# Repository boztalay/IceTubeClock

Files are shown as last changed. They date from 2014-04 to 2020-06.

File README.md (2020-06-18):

IceTubeClock
============

A clock with ice tubes for its display

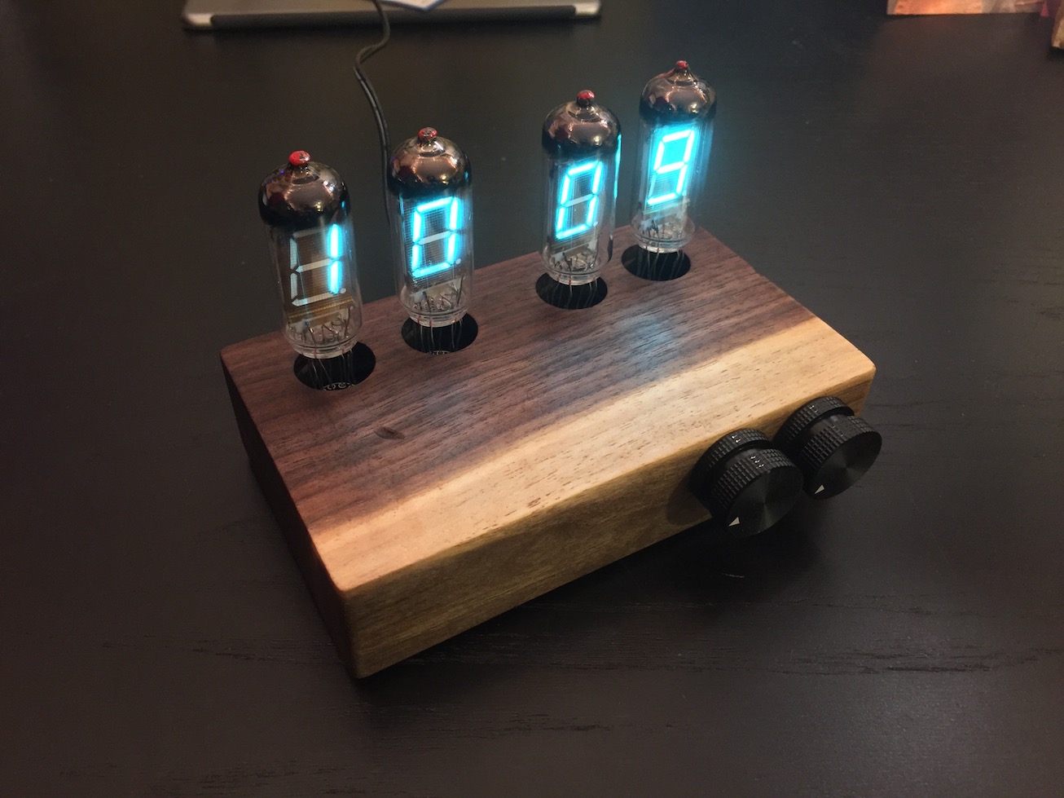
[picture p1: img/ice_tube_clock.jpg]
Final clock


Milling the enclosure:
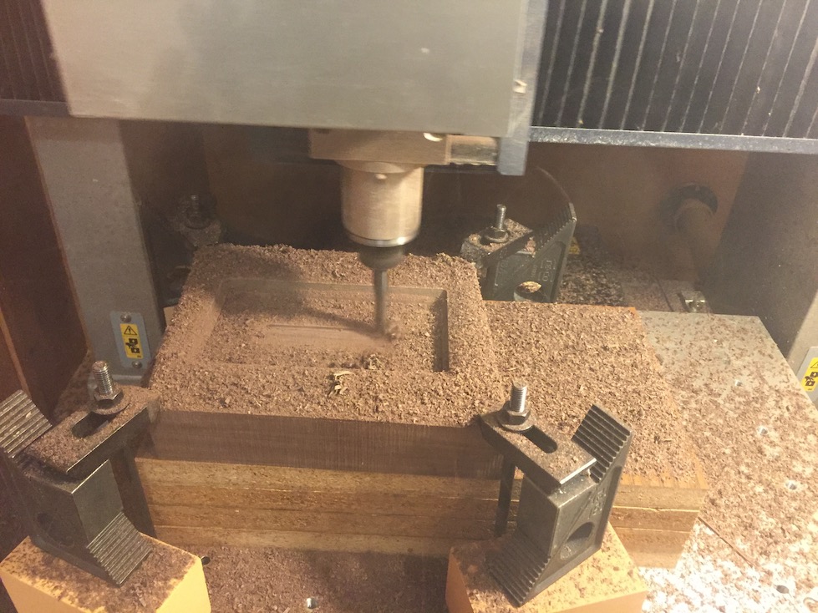
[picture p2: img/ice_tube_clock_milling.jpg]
Milling the enclosure


Milling the base PCB:
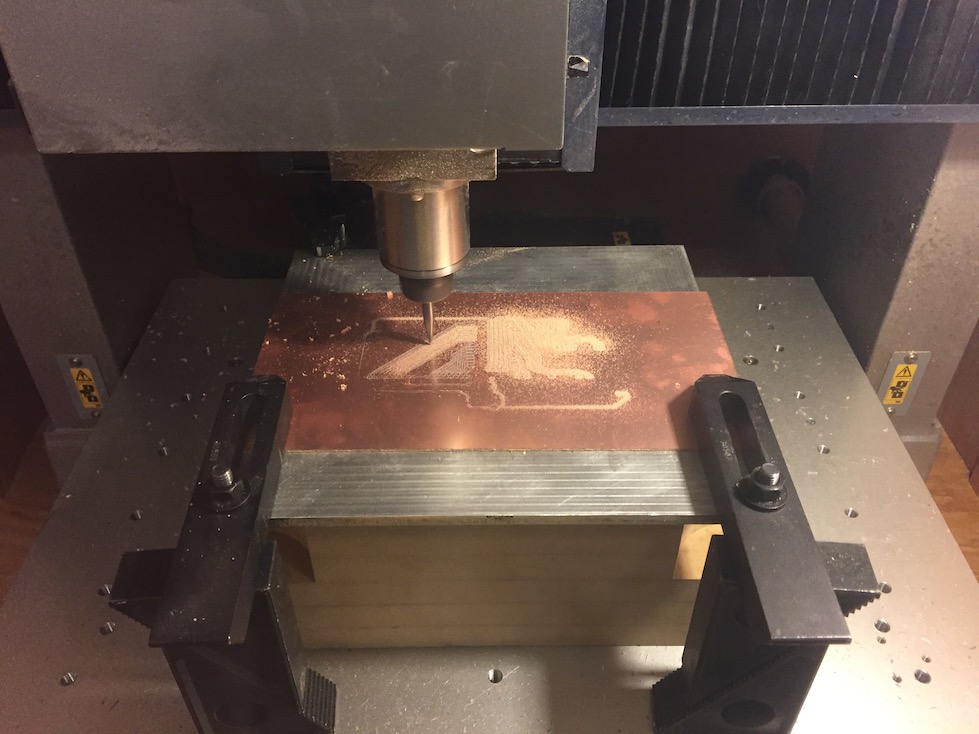
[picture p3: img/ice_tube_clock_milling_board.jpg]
Milling the base PCB


Drilling the base PCB:
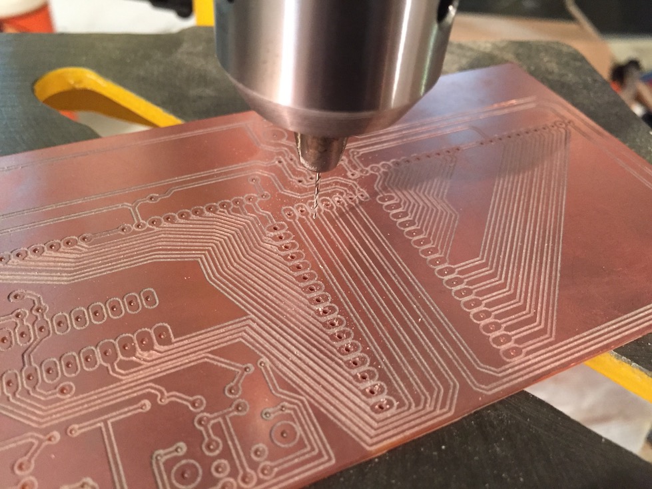
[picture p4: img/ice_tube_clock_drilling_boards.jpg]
Drilling the base PCB


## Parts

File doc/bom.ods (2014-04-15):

Ice Tube Clock v1.0 Bill of Materials
Module | Part | Description | Quantity | Source
Microcontroller
 | ATMEGA168A-PU | ATmega168 | 1 | http://www.digikey.com/product-search/en?site=us&mpart=ATMEGA168A-PU&v=313
 | 100 nF cap (104) | Power filter capacitor | 1 | Parts bin
 | 10k resistor | Pull-up resistor on reset | 1 | Parts bin
Main Power Supply (12v)
 | EPSA120200U-P5P-SZ | 12v wall adapter | 1 | http://www.digikey.com/product-detail/en/EPSA120200U-P5P-SZ/T1071-P5P-ND/2235263
 | PJ-037A | Barrel jack adapter | 1 | http://www.digikey.com/product-detail/en/PJ-037A/CP-037A-ND/1644545
 | T102SHCQE | Power switch | 1 | http://www.digikey.com/product-detail/en/T102SHCQE/CKN10151-ND/2044437
 | DF206ST-G | Bridge rectifier | 1 | http://www.digikey.com/product-detail/en/DF206ST-G/641-1425-1-ND/2208797
 | 100 nF cap (104) | Filter cap | 1 | Parts bin
5v Power Supply
 | LM7805CT | 5v voltage regulator | 1 | http://www.digikey.com/product-detail/en/LM7805CT/LM7805CT-ND/458698
 | UVP0J331MPD1TD | 330uF capacitor | 2 | http://www.digikey.com/product-detail/en/UVP0J331MPD1TD/493-12666-1-ND/4328283
 | 1N5817-TP | Backvoltage protection diode | 1 | http://www.digikey.com/product-detail/en/1N5817-TP/1N5817-TPCT-ND/950586
 | 100 nF cap (104) | Filter cap | 1 | Parts bin
60v Power Supply
 | ESH476M025AC3AA | 47uF 25v capacitor | 1 | http://www.digikey.com/product-detail/en/ESH476M025AC3AA/399-6587-ND/3083002
 | 10k resistor | Pull-down resistor | 1 | Parts bin
 | 100 nF cap (104) | Filter cap | 1 | Parts bin
 | AIUR-04-222J | Inductor | 1 | http://www.digikey.com/product-detail/en/AIUR-04-222J/AIUR-04-222J-ND/2343558
 | IRF540NSPBF | Switching FET | 1 | http://www.digikey.com/product-detail/en/IRF540NSPBF/IRF540NSPBF-ND/812047
 | MBR160RLG | Schottky diode | 1 | http://www.digikey.com/product-detail/en/MBR160RLG/MBR160RLGOSCT-ND/807341
 | 1N5264B-TP | Zener diode | 1 | http://www.digikey.com/product-detail/en/1N5264B-TP/1N5264B-TPCT-ND/950575
 | ECA-2AM101 | 100uF 100v capacitor | 1 | http://www.digikey.com/product-detail/en/ECA-2AM101/P5313-ND/245067
Tubes/Tube Driver
 | IV-11 | VFD tube | 6 | eBay
 | ERX-3SJ9R1 | 3W resistor | 1 | http://www.digikey.com/product-detail/en/ERX-3SJ9R1/P9.1W-3BK-ND/36640
 | MAX6921AUI+ | Tube segment/grid drivers | 3 | http://www.digikey.com/product-detail/en/MAX6921AUI%2B/MAX6921AUI%2B-ND/1512611
 | ZVP3306FTA | Driver power switch | 1 | http://www.digikey.com/product-detail/en/ZVP3306FTA/ZVP3306FCT-ND/92640

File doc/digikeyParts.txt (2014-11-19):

http://www.digikey.com/product-search/en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
http://www.digikey.com/product-detail/en/0AGA002.V/F5006-ND/2519251
http://www.digikey.com/product-detail/en/LM555CN/LM555CNFS-ND/458696
http://www.digikey.com/product-detail/en/ERJ-8GEYJ103V/P10KECT-ND/203249
http://www.digikey.com/product-detail/en/C1206C103JARACTU/399-7174-1-ND/3439312
http://www.digikey.com/product-detail/en/ERJ-8GEYJ101V/P100ECT-ND/203247
http://www.digikey.com/product-detail/en/TS53YL103MR10/TS53YL-10KCT-ND/1587993
http://www.digikey.com/product-detail/en/LM555CM/LM555CMFS-ND/1051271
http://www.digikey.com/product-detail/en/M50-2000005/952-1731-ND/2890859
http://www.digikey.com/product-detail/en/ERJ-8GEYJ114V/P110KECT-ND/203256

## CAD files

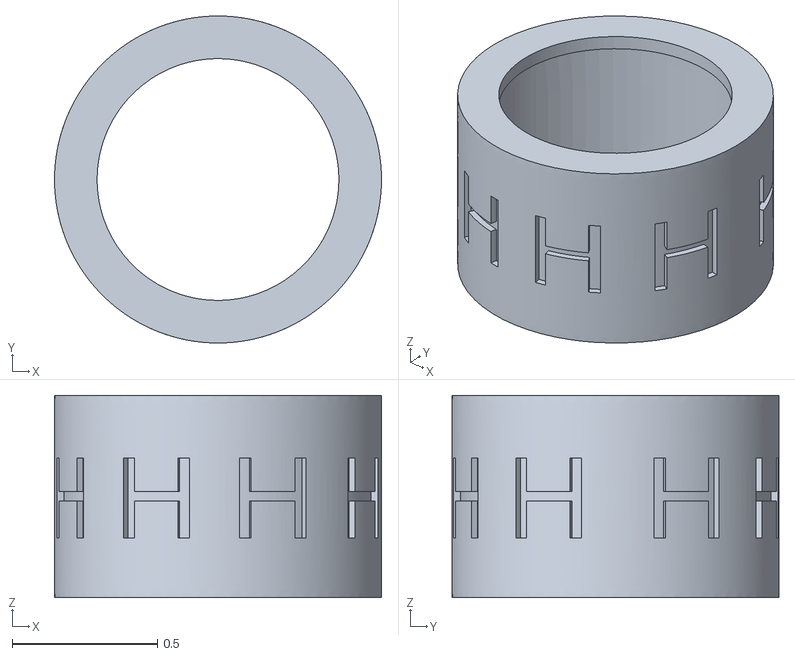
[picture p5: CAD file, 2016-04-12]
case/hourKnob.stl
1.13 x 1.13 x 0.696

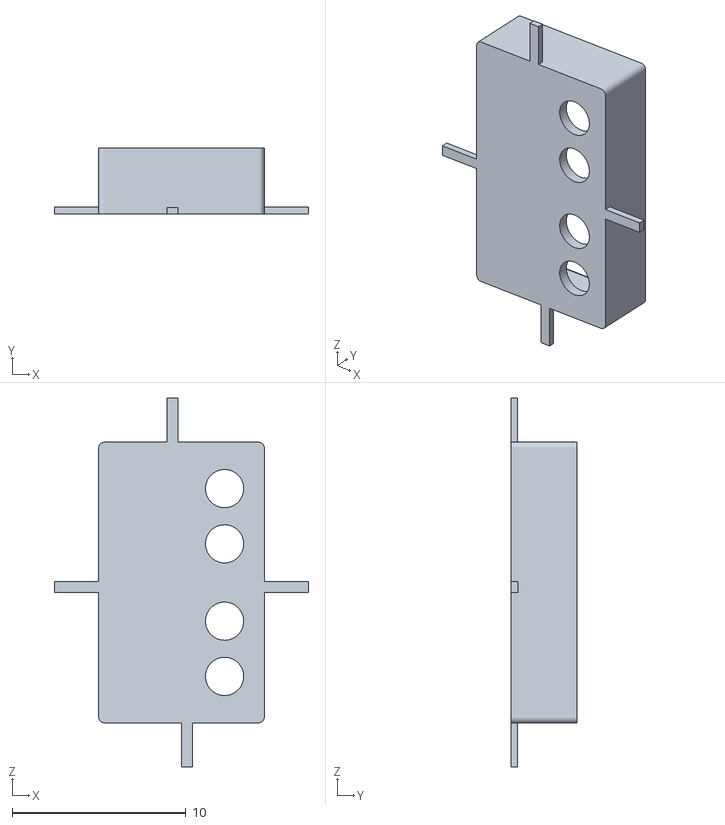
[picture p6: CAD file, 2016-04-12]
case/iceTubeClockBaseRevised.stl
14.6 x 3.81 x 21.2

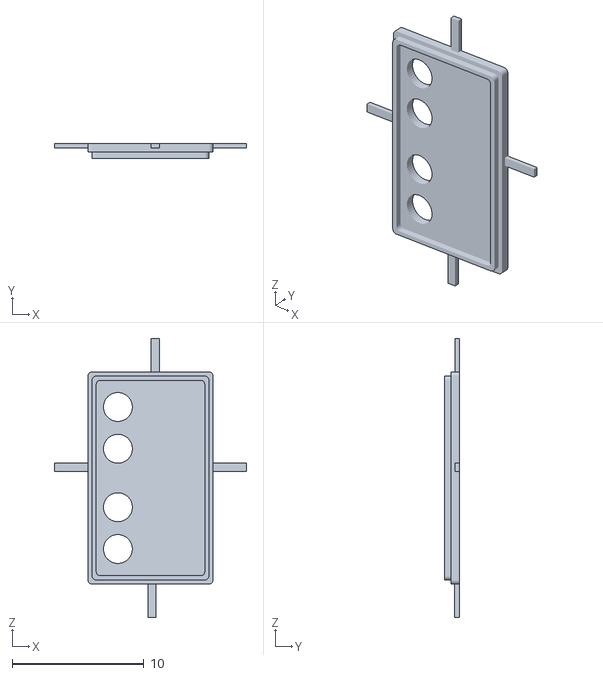
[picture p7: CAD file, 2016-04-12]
case/iceTubeClockTop.stl
14.6 x 1.11 x 21.2

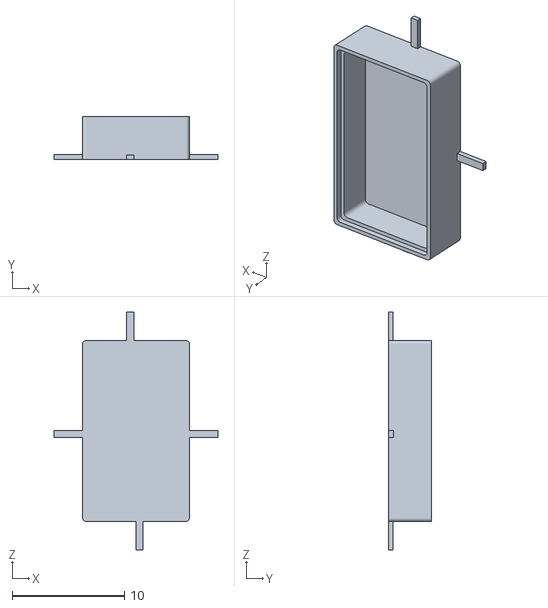
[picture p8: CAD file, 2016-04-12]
case/iceTubeClockBase.stl
14.6 x 3.81 x 21.2

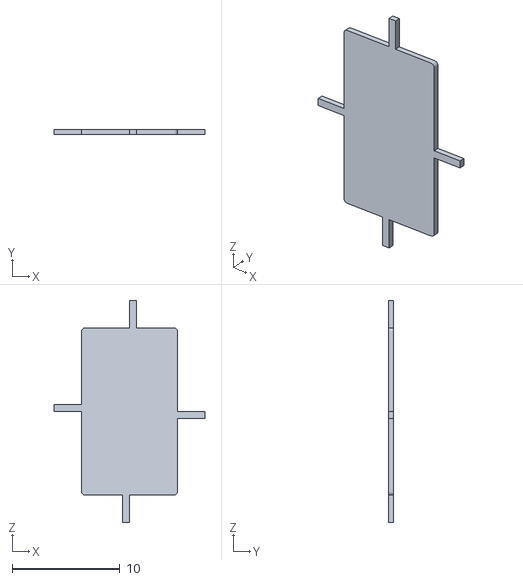
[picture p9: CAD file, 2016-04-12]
case/iceTubeClockTopRevised.stl
14.0 x 0.476 x 20.6

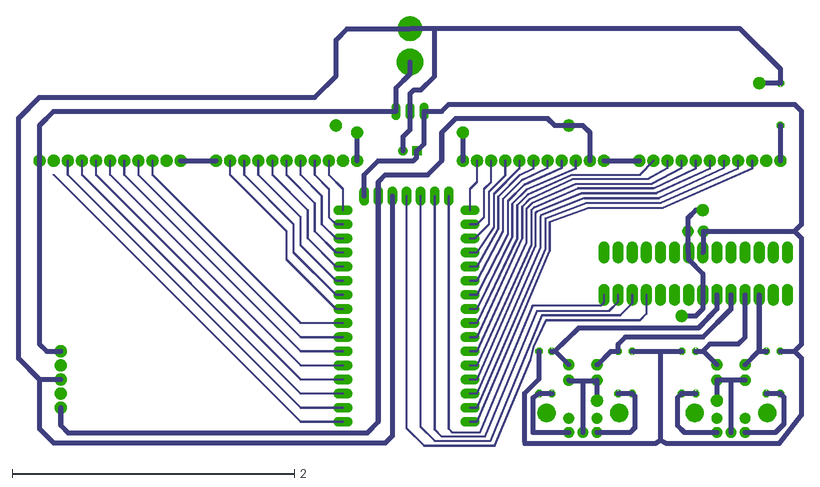
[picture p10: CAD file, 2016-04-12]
case/ice_tube_clock.dxf
5.58 x 3.05

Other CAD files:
case/minuteKnob.stl
case/iceTubeClockAssembly.iam
case/iceTubeClockAssemblyRevised.iam
case/iceTubeClockBase.3dm
case/iceTubeClockBase.ipt
case/iceTubeClockBaseRevised.3dm
case/iceTubeClockBaseRevised.ipt
case/iceTubeClockTop.3dm
case/iceTubeClockTop.ipt
case/iceTubeClockTopRevised.3dm
case/iceTubeClockTopRevised.ipt
case/knobs.3dm
pcb/ice_tube_clock/iceTubeClockCircuitBoard.3dm

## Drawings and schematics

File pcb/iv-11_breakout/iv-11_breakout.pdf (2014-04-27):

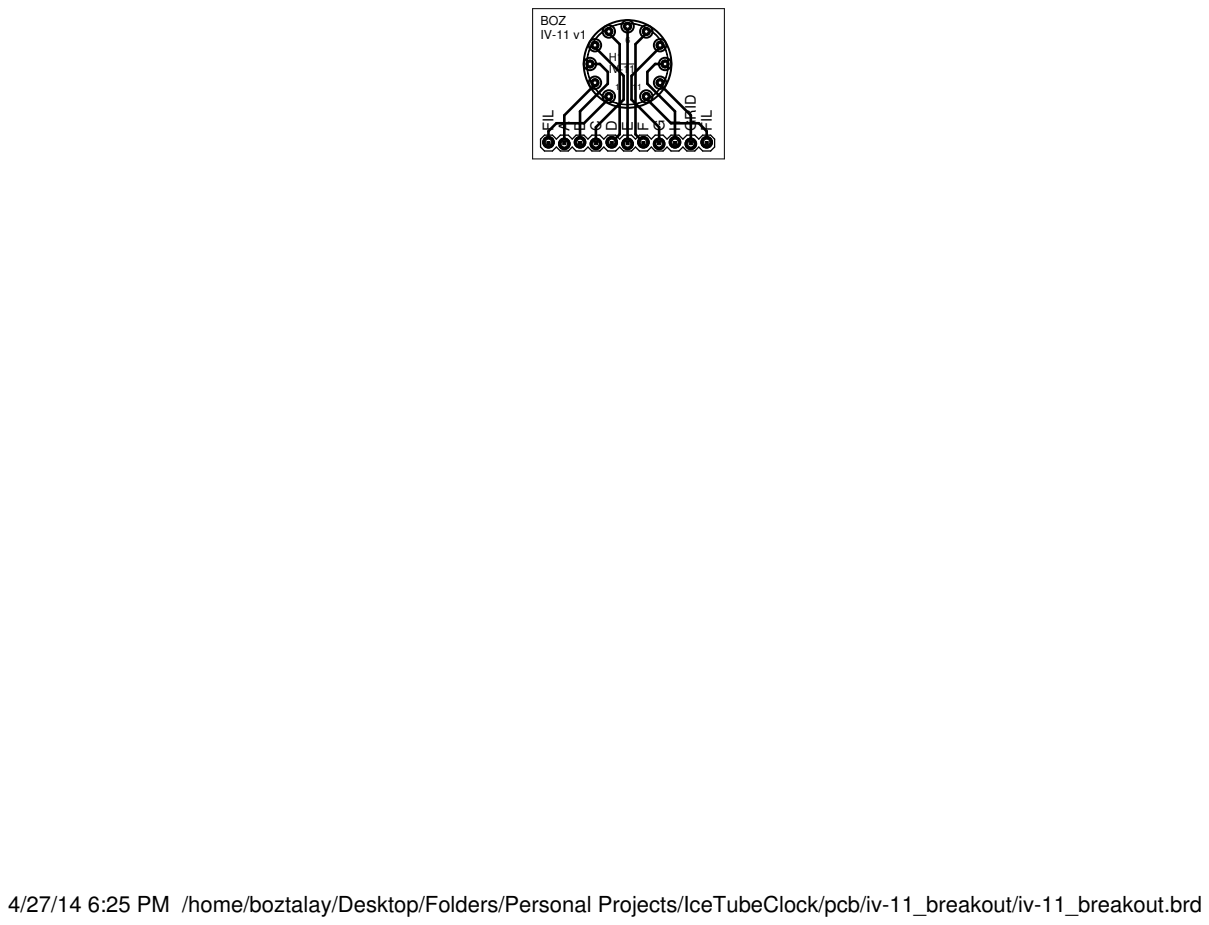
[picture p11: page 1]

4/27/14 6:25 PM /home/boztalay/Desktop/Folders/Personal Projects/IceTubeClock/pcb/iv-11_breakout/iv-11_breakout.brd

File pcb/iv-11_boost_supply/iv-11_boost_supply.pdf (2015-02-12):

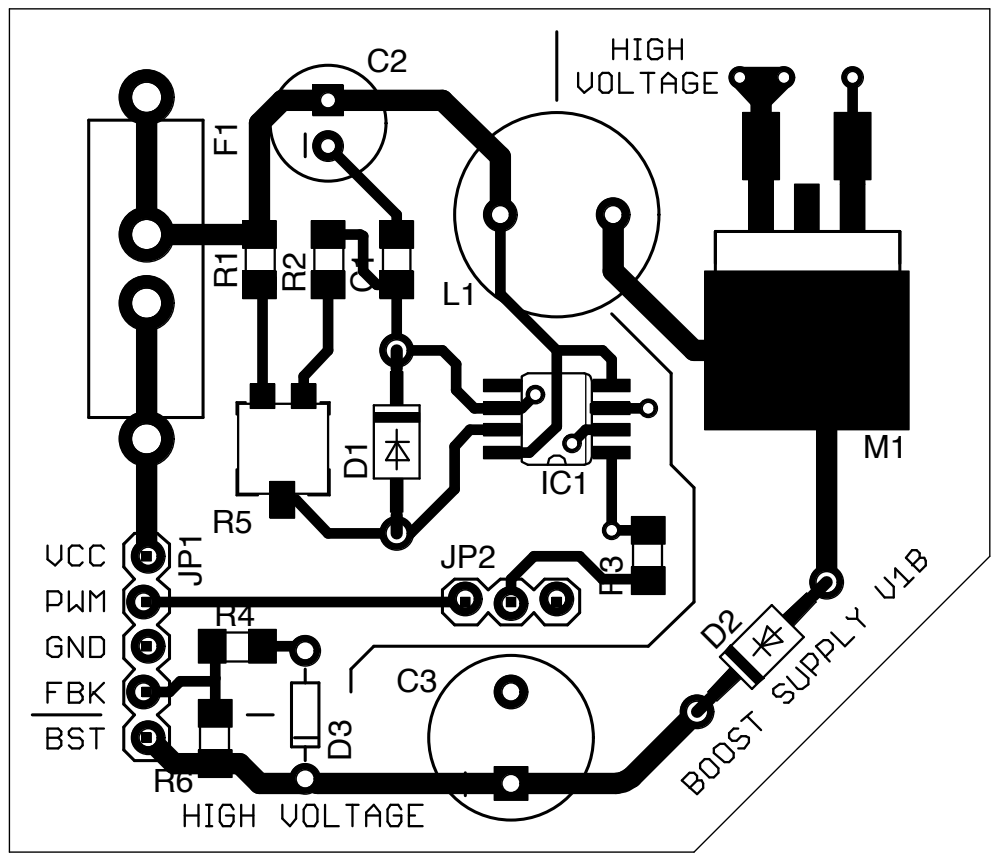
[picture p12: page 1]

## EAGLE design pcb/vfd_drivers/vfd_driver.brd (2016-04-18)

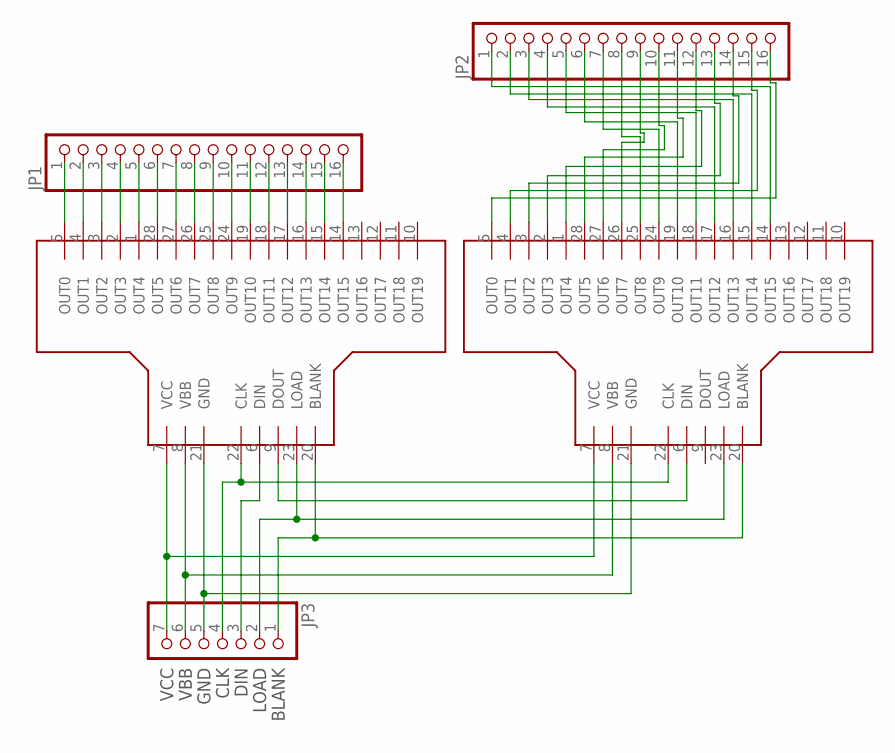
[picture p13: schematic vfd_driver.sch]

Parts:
JP1, JP2: PINHD-1X16; 1X16
JP3: PINHD-1X7; 1X07
U$1, U$2: MAX6921/31; TSSOP-28

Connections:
BLANK: JP3.1, U$1.20 (BLANK), U$2.20 (BLANK)
CLK: JP3.4, U$1.22 (CLK), U$2.22 (CLK)
DIN: JP3.3, U$1.6 (DIN)
DINOUT: U$1.9 (DOUT), U$2.6 (DIN)
GND: JP3.5, U$1.21 (GND), U$2.21 (GND)
LOAD: JP3.2, U$1.23 (LOAD), U$2.23 (LOAD)
unnamed: JP2.1, U$2.14 (OUT15)
unnamed: JP2.2, U$2.15 (OUT14)
unnamed: JP2.3, U$2.16 (OUT13)
unnamed: JP2.4, U$2.17 (OUT12)
unnamed: JP2.5, U$2.18 (OUT11)
unnamed: JP2.6, U$2.19 (OUT10)
unnamed: JP2.7, U$2.24 (OUT9)
unnamed: JP2.8, U$2.25 (OUT8)
unnamed: JP2.9, U$2.26 (OUT7)
unnamed: JP2.10, U$2.27 (OUT6)
unnamed: JP2.11, U$2.28 (OUT5)
unnamed: JP2.12, U$2.1 (OUT4)
unnamed: JP2.13, U$2.2 (OUT3)
unnamed: JP2.14, U$2.3 (OUT2)
unnamed: JP2.15, U$2.4 (OUT1)
unnamed: JP2.16, U$2.5 (OUT0)
unnamed: JP1.16, U$1.14 (OUT15)
unnamed: JP1.15, U$1.15 (OUT14)
unnamed: JP1.14, U$1.16 (OUT13)
unnamed: JP1.13, U$1.17 (OUT12)
unnamed: JP1.12, U$1.18 (OUT11)
unnamed: JP1.11, U$1.19 (OUT10)
unnamed: JP1.10, U$1.24 (OUT9)
unnamed: JP1.9, U$1.25 (OUT8)
unnamed: JP1.8, U$1.26 (OUT7)
unnamed: JP1.7, U$1.27 (OUT6)
unnamed: JP1.6, U$1.28 (OUT5)
unnamed: JP1.5, U$1.1 (OUT4)
unnamed: JP1.4, U$1.2 (OUT3)
unnamed: JP1.3, U$1.3 (OUT2)
unnamed: JP1.2, U$1.4 (OUT1)
unnamed: JP1.1, U$1.5 (OUT0)
VBB: JP3.6, U$1.8 (VBB), U$2.8 (VBB)
VCC: JP3.7, U$1.7 (VCC), U$2.7 (VCC)

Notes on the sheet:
VCC
VBB
GND
CLK
DIN
LOAD
BLANK

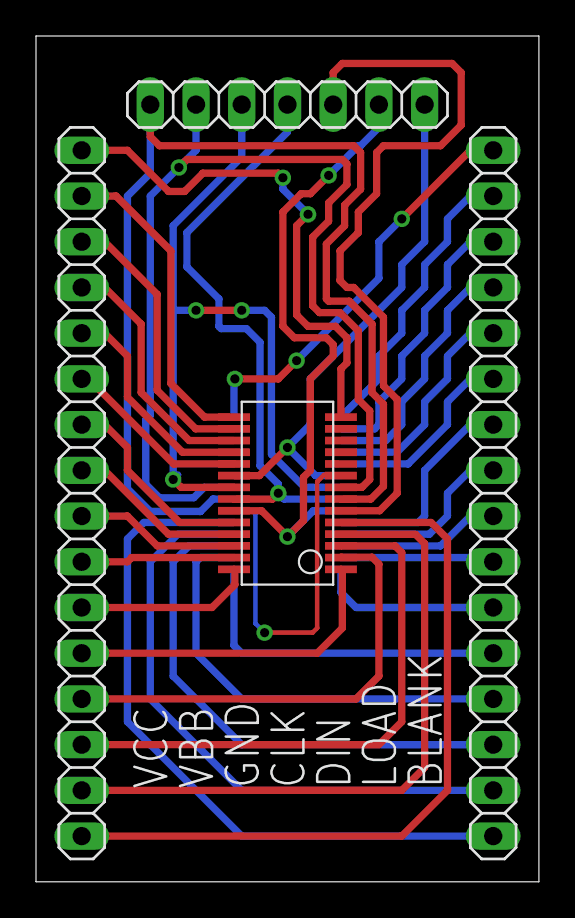
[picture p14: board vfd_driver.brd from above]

Board: 2 copper layers, 27.9 x 47.0 mm, 5 parts (1 on the bottom side), 40 nets.

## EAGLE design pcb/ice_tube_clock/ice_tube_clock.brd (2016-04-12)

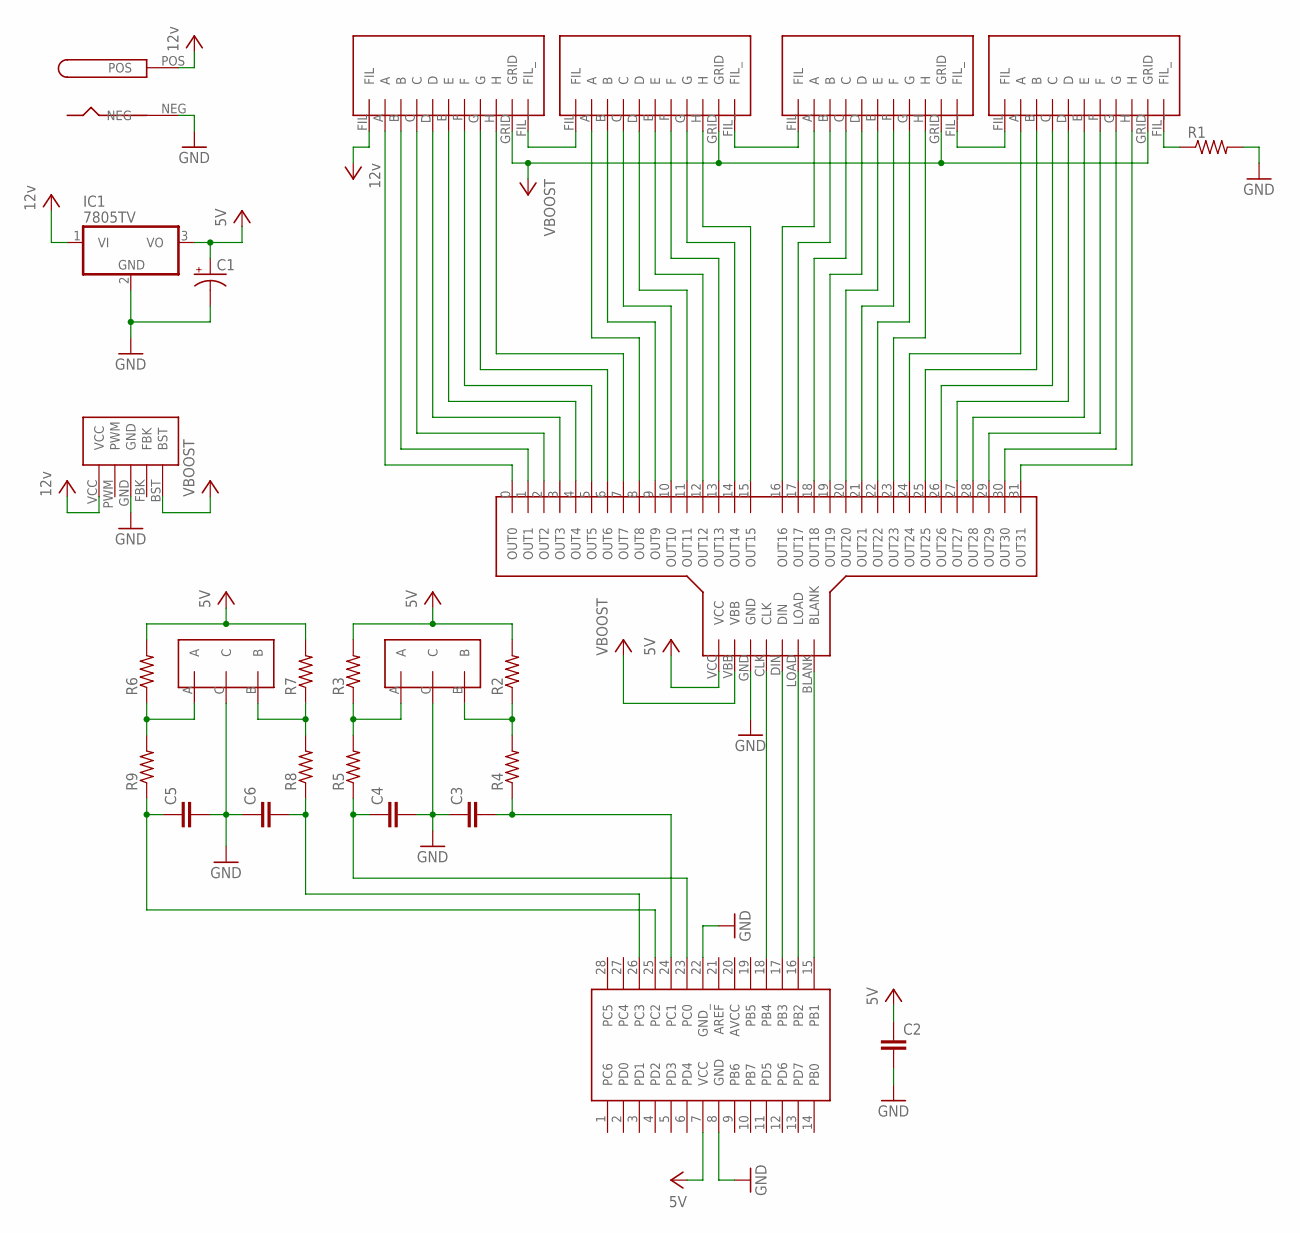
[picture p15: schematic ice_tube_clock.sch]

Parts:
C1: CAP_POLPTH1; CPOL-RADIAL-100UF-25V
C2, C3, C4, C5, C6: 0.1UF-50V-20%(PTH)KIT-EZ; CAP-PTH-SMALL-KIT
IC1: 7805TV; TO220V
R1, R2, R3, R4, R5, R6, R7, R8, R9: R-US_0204/7; 0204/7
U$1: ATMEGA168-DIP28; DIP28
U$2: IV11-BOOST-SUPPLY
U$3, U$4, U$5, U$6: IV-11-CARRIER
U$7: PJ-037A
U$8: VFD-DRIVER-CARRIER
U$9, U$10: PEL12S

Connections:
+5V: C1.1 (+), C2.1, IC1.3 (VO), R2.2, R3.2, R6.2, R7.2, U$1.7 (VCC), U$8.VCC
+12V: IC1.1 (VI), U$2.VCC, U$3.FIL, U$7.POS
ET: C4.1, R5.1, U$1.23 (PC0)
GND: C1.2 (-), C2.2, C3.1, C4.2, C5.2, C6.1, IC1.2 (GND), R1.2, U$1.8 (GND), U$1.22 (GND_), U$2.GND, U$7.NEG, U$8.GND, U$9.C, U$10.C
unnamed: U$3.FIL_, U$4.FIL
unnamed: U$4.FIL_, U$5.FIL
unnamed: U$5.FIL_, U$6.FIL
unnamed: U$3.A, U$8.0 (OUT0)
unnamed: U$3.B, U$8.1 (OUT1)
unnamed: U$3.C, U$8.2 (OUT2)
unnamed: U$3.D, U$8.3 (OUT3)
unnamed: U$3.E, U$8.4 (OUT4)
unnamed: U$3.F, U$8.5 (OUT5)
unnamed: U$3.G, U$8.6 (OUT6)
unnamed: U$3.H, U$8.7 (OUT7)
unnamed: U$4.A, U$8.8 (OUT8)
unnamed: U$4.B, U$8.9 (OUT9)
unnamed: U$4.C, U$8.10 (OUT10)
unnamed: U$4.D, U$8.11 (OUT11)
unnamed: U$4.E, U$8.12 (OUT12)
unnamed: U$4.F, U$8.13 (OUT13)
unnamed: U$4.G, U$8.14 (OUT14)
unnamed: U$4.H, U$8.15 (OUT15)
unnamed: U$6.H, U$8.31 (OUT31)
unnamed: U$6.G, U$8.30 (OUT30)
unnamed: U$6.F, U$8.29 (OUT29)
unnamed: U$6.E, U$8.28 (OUT28)
unnamed: U$6.D, U$8.27 (OUT27)
unnamed: U$6.C, U$8.26 (OUT26)
unnamed: U$6.B, U$8.25 (OUT25)
unnamed: U$6.A, U$8.24 (OUT24)
unnamed: U$5.H, U$8.23 (OUT23)
unnamed: U$5.G, U$8.22 (OUT22)
unnamed: U$5.F, U$8.21 (OUT21)
unnamed: U$5.E, U$8.20 (OUT20)
unnamed: U$5.D, U$8.19 (OUT19)
unnamed: U$5.C, U$8.18 (OUT18)
unnamed: U$5.B, U$8.17 (OUT17)
unnamed: U$5.A, U$8.16 (OUT16)
unnamed: R1.1, U$6.FIL_
unnamed: U$1.15 (PB1), U$8.BLANK
unnamed: U$1.16 (PB2), U$8.LOAD
unnamed: U$1.17 (PB3), U$8.DIN
unnamed: U$1.18 (PB4), U$8.CLK
unnamed: C3.2, R4.1, U$1.24 (PC1)
unnamed: R3.1, R5.2, U$10.A
unnamed: R6.1, R9.2, U$9.A
unnamed: R7.1, R8.2, U$9.B
unnamed: R2.1, R4.2, U$10.B
unnamed: C5.1, R9.1, U$1.25 (PC2)
unnamed: C6.2, R8.1, U$1.26 (PC3)
VBOOST: U$2.BST, U$3.GRID, U$4.GRID, U$5.GRID, U$6.GRID, U$8.VBB

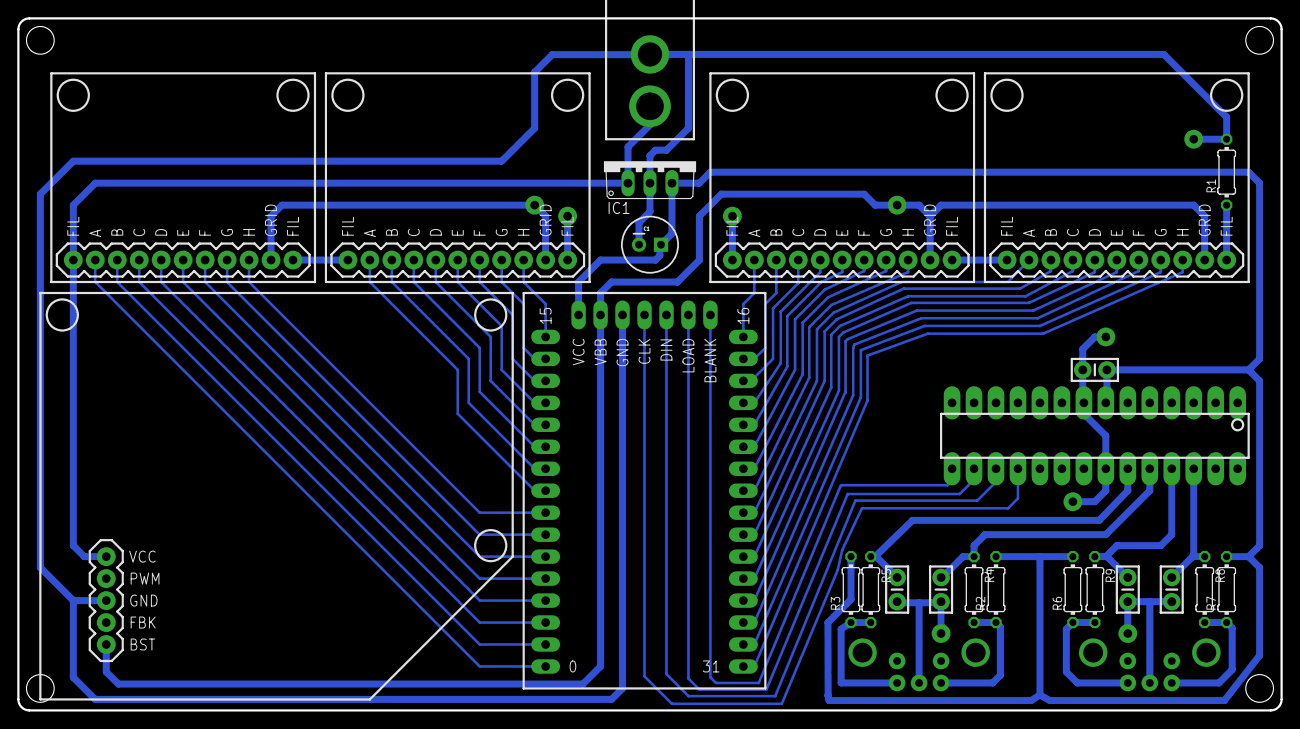
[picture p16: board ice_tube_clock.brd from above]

Board: 2 copper layers, 146.1 x 80.0 mm, 26 parts (0 on the bottom side), 52 nets.

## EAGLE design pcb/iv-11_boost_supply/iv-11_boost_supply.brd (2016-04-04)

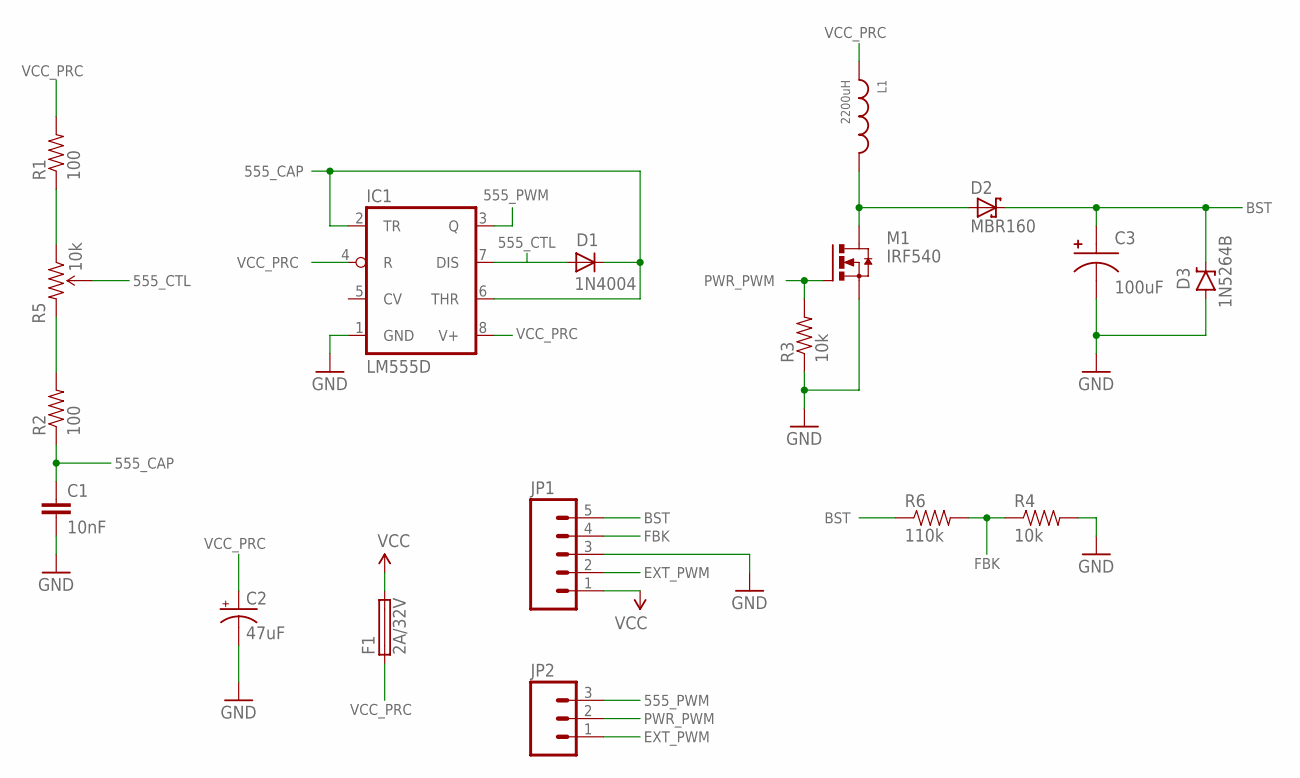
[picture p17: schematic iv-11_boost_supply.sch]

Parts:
C1: 10nF; 1206
C2: 47uF; CPOL-RADIAL-100UF-25V
C3: 100uF; POLAR-CAP-PTH-10MM
D1: 1N4004; DO41-10
D2: MBR160; DO41-10
D3: 1N5264B; DIODE-ZENER
F1: 2A/32V; 1AG-1/4X5/8-FUSE
IC1: LM555D; SO08
JP1: M05LOCK; 1X05_LOCK
JP2: M03LOCK; 1X03_LOCK
L1: 2200uH; INDUCTOR-PTH-13MM
M1: IRF540; D2PACK
R1, R2: 100; 1206
R3, R4: 10k; 1206
R5: 10k; TRIMPOT-5MM-V2
R6: 110k; 1206

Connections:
555_CAP: C1.1, D1.C, IC1.2 (TR), IC1.6 (THR), R2.1
555_CTL: D1.A, IC1.7 (DIS), R5.B (WIPER)
555_PWM: IC1.3 (Q), JP2.3
BST: C3.A, D2.C, D3.P$1 (C), JP1.5, R6.1
EXT_PWM: JP1.2, JP2.1
FBK: JP1.4, R4.1, R6.2
GND: C1.2, C2.2 (-), C3.B, D3.P$2 (A), IC1.1 (GND), JP1.3, M1.3 (S), R3.1, R4.2
unnamed: R1.1, R5.A (CCW)
unnamed: R2.2, R5.C (CW)
unnamed: D2.A, L1.B, M1.2 (D)
PWR_PWM: JP2.2, M1.1 (G), R3.2
VCC: F1.P$3 (2), F1.P$4 (2), JP1.1
VCC_PRC: C2.1 (+), F1.P$1 (1), F1.P$2 (1), IC1.4 (R), IC1.8 (V+), L1.A, R1.2

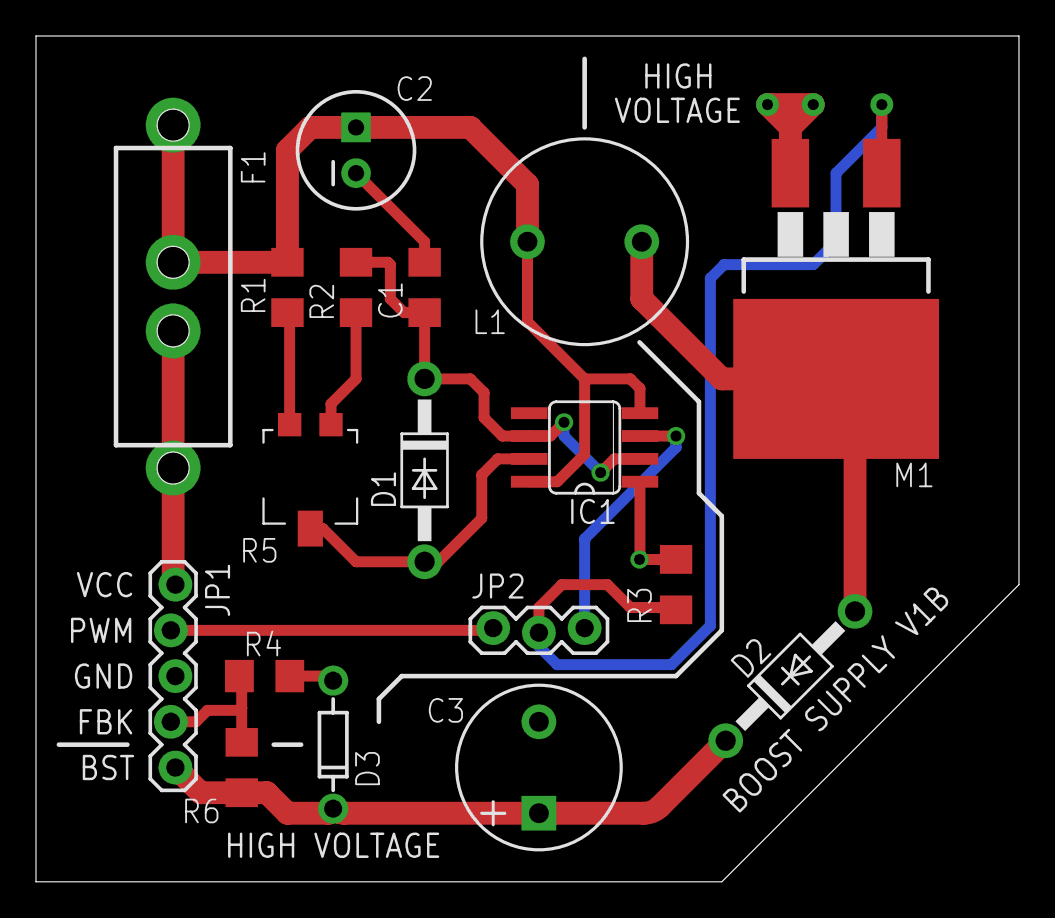
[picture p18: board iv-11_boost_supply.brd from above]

Board: 2 copper layers, 54.6 x 47.0 mm, 18 parts (0 on the bottom side), 13 nets.

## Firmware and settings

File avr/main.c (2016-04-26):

#ifndef F_CPU
#define F_CPU 8000000UL
#endif

#include <avr/io.h>
#include <util/delay.h>
#include <avr/interrupt.h>

// NOTE: Programming command is of the form
//  avrdude -p m168 -P /dev/cu.usbmodem14111 -c avrisp -b 19200 -U flash:w:main.hex

// Patterns for each number on the tubes

uint8_t numberPatterns[10][8] = {
  // A  B  C  D  E  F  G  H
    {1, 1, 1, 0, 1, 1, 0, 1}, // 0
    {0, 0, 0, 0, 0, 1, 0, 1}, // 1
    {1, 1, 0, 1, 1, 1, 0, 0}, // 2
    {1, 0, 0, 1, 1, 1, 0, 1}, // 3
    {0, 0, 1, 1, 0, 1, 0, 1}, // 4
    {1, 0, 1, 1, 1, 0, 0, 1}, // 5
    {1, 1, 1, 1, 1, 0, 0, 1}, // 6
    {0, 0, 0, 0, 1, 1, 0, 1}, // 7
    {1, 1, 1, 1, 1, 1, 0, 1}, // 8
    {1, 0, 1, 1, 1, 1, 0, 1}, // 9
};

// Globals for keeping track of the current time

int8_t hours;
int8_t minutes;

// Global to keep track of how many seconds
// have passed

uint8_t secondsPassed;

// Struct and globals to keep track of the state
// of the hour and minute knobs

typedef enum {
    NONE,
    INCREMENT,
    DECREMENT
} KnobMovement;

typedef enum {
    NO_EDGE,
    RISING,
    FALLING
} KnobChannelEdge;

typedef struct {
    uint8_t lastChannelA;
    uint8_t channelA;
    KnobChannelEdge channelAEdge;

    uint8_t lastChannelB;
    uint8_t channelB;
    KnobChannelEdge channelBEdge;
} KnobState;

KnobState hourKnobState;
KnobState minuteKnobState;

// Function declarations

void setUpSystemClock(void);

void setUpKnobInterface(void);
void readKnobs(void);
void checkKnobs(void);
void checkKnobStateForEdges(KnobState*);
KnobMovement checkKnobStateForMovement(KnobState*);

void setUpRealTimeClock(void);
void updateTime(void);
void incrementTime(void);
uint8_t incrementMinutes(void);
uint8_t incrementHours(void);
uint8_t decrementMinutes(void);
uint8_t decrementHours(void);


void setUpTubeDriverInterface(void);
void waitForTubeWarmup(void);
void updateTubes(void);
void sendBitsToTubeDriversToDisplayNumber(int8_t, uint8_t);
void sendBitToTubeDrivers(uint8_t);
void latchTubeDrivers(void);

// Main

int main(void) {
	setUpSystemClock();
    setUpKnobInterface();
	setUpTubeDriverInterface();

	waitForTubeWarmup();

    hours = 12;
    minutes = 0;

    setUpRealTimeClock();

    updateTubes();

	while(1) {
        _delay_ms(3); // Quick and dirty debounce on the knobs
        checkKnobs();
	}
}

// Initialization

void setUpSystemClock() {
	// Notify it that we want to change the prescaler
	CLKPR = _BV(CLKPCE);

	// Set the prescaler to 1 (should give us 8MHz)
	CLKPR = 0x00;
}

// Interfacing with the hour and minute adjustment knobs

void setUpKnobInterface() {
    // Pins
    // PORTC.0  Hour Knob A
    // PORTC.1  Hour Knob B
    // PORTC.2  Minute Knob A
    // PORTC.3  Minute Knob B

    // Set up all of the interface pins as inputs with no pull-up resistors
    DDRC = 0x00;
    PORTC = 0x00;

    // Take an initial reading of the knobs
    readKnobs();
}

void readKnobs() {
    // Copy the current states over into the last states
    hourKnobState.lastChannelA = hourKnobState.channelA;
    hourKnobState.lastChannelB = hourKnobState.channelB;
    minuteKnobState.lastChannelA = minuteKnobState.channelA;
    minuteKnobState.lastChannelB = minuteKnobState.channelB;

    // Read the current states
    hourKnobState.channelA = (PINC & _BV(PINC0)) ? 1 : 0;
    hourKnobState.channelB = (PINC & _BV(PINC1)) ? 1 : 0;
    minuteKnobState.channelA = (PINC & _BV(PINC2)) ? 1 : 0;
    minuteKnobState.channelB = (PINC & _BV(PINC3)) ? 1 : 0;
}

void checkKnobs() {
    // First read the current state of the knob pins
    readKnobs();

    // Check if any of the knob pins have changed state
    checkKnobStateForEdges(&hourKnobState);
    checkKnobStateForEdges(&minuteKnobState);

    // Check if either of the knobs have registered movement
    KnobMovement hourKnobMovement = checkKnobStateForMovement(&hourKnobState);
    KnobMovement minuteKnobMovement = checkKnobStateForMovement(&minuteKnobState);

    // Handle increments and decrements accordingly
    // This is gross, needs to be redone

    if(hourKnobMovement == INCREMENT) {
        incrementHours();
        updateTubes();
    } else if(hourKnobMovement == DECREMENT) {
        decrementHours();
        updateTubes();
    }

    if(minuteKnobMovement == INCREMENT) {
        incrementMinutes();
        updateTubes();
    } else if(minuteKnobMovement == DECREMENT) {
        decrementMinutes();
        updateTubes();
    }
}

void checkKnobStateForEdges(KnobState* knobState) {
    if(knobState->lastChannelA != knobState->channelA) {
        knobState->channelAEdge = (knobState->channelA == 1) ? RISING : FALLING;
    } else {
        knobState->channelAEdge = NO_EDGE;
    }

    if(knobState->lastChannelB != knobState->channelB) {
        knobState->channelBEdge = (knobState->channelB == 1) ? RISING : FALLING;
    } else {
        knobState->channelBEdge = NO_EDGE;
    }
}

KnobMovement checkKnobStateForMovement(KnobState* knobState) {
    // Not doing classic quadrature decoding so that I can tune
    // the feel of the knobs for incrementing and decrementing.
    // Different parts of the quadrature cycle match the detents
    // on the knobs for incrementing or decrementing.

    if(knobState->channelAEdge == RISING && knobState->channelB == 1) {
        return DECREMENT;
    }
    if(knobState->channelBEdge == RISING && knobState->channelA == 1) {
        return INCREMENT;
    }

    return NONE;
}

// Keeping track of time

void setUpRealTimeClock() {
    // Set up Timer 2 to use an external clock source
    // and a prescaler of 128, which gives 1 overflow
    // interrupt per second
    TCCR2A = 0x00;
    TCCR2B = 0x05;

    // Clear Timer 2's counter
    TCNT2 = 0;

    // Enable the overflow interrupt
    TIMSK2 |= 0x01;

    // Enable asynchronous mode for the timer
    ASSR = 0x20;

    // Reset the seconds counter
    secondsPassed = 0;

    // Enable global interrupts
    sei();
}

ISR(TIMER2_OVF_vect) {
    // Happens once per second
    secondsPassed++;

    if(secondsPassed >= 60) {
        secondsPassed = 0;
        updateTime();
    }
}

void updateTime() {
    incrementTime();
    updateTubes();
}

void incrementTime() {
    uint8_t minutesOverflow = incrementMinutes();
    if(minutesOverflow == 1) {
        incrementHours();
    }
}

uint8_t incrementMinutes() {
    minutes++;

    if(minutes > 59) {
        minutes = 0;
        return 1;
    } else {
        return 0;
    }
}

uint8_t incrementHours() {
    hours++;

    if(hours > 12) {
        hours = 1;
        return 1;
    } else {
        return 0;
    }
}

uint8_t decrementMinutes() {
    minutes--;

    if(minutes < 0) {
        minutes = 59;
        return 1;
    } else {
        return 0;
    }
}

uint8_t decrementHours() {
    hours--;

    if(hours < 1) {
         hours = 12;
         return 1;
    } else {
         return 0;
    }
}

// Interfacing with the tube drivers

// Drivers are connected to the tubes like so:
// OUT0     Tube 0 A
// OUT1     Tube 0 B
// OUT2     Tube 0 C
// OUT3     Tube 0 D
// OUT4     Tube 0 E
// OUT5     Tube 0 F
// OUT6     Tube 0 G
// OUT7     Tube 0 H
// OUT8     Tube 1 A
// OUT9     Tube 1 B
// OUT10    Tube 1 C
// OUT11    Tube 1 D
// OUT12    Tube 1 E
// OUT13    Tube 1 F
// OUT14    Tube 1 G
// OUT15    Tube 1 H
// OUT16    NC
// OUT17    NC
// OUT18    NC
// OUT19    NC
// OUT0     Tube 3 H
// OUT1     Tube 3 G
// OUT2     Tube 3 F
// OUT3     Tube 3 E
// OUT4     Tube 3 D
// OUT5     Tube 3 C
// OUT6     Tube 3 B
// OUT7     Tube 3 A
// OUT8     Tube 2 H
// OUT9     Tube 2 G
// OUT10    Tube 2 F
// OUT11    Tube 2 E
// OUT12    Tube 2 D
// OUT13    Tube 2 C
// OUT14    Tube 2 B
// OUT15    Tube 2 A
// OUT16    NC
// OUT17    NC
// OUT18    NC
// OUT19    NC

void setUpTubeDriverInterface() {
	// Pins     PCB         Breadboard
	// PORTB.4	CLK         (DIN)
	// PORTB.3	DIN         (LOAD)
	// PORTB.2	LOAD        (CLK)
	// PORTB.1	BLANK       (BLANK)

	// Set up all of the interface pins as output, outputs to 0
	DDRB = _BV(DDB4) | _BV(DDB3) | _BV(DDB2) | _BV(DDB1);
	PORTB = 0x00;
}

void waitForTubeWarmup() {
	_delay_ms(1000);
}

void updateTubes() {
    int8_t hoursTensDigit = hours / 10;
    int8_t hoursOnesDigit = hours - (hoursTensDigit * 10);
    int8_t minutesTensDigit = minutes / 10;
    int8_t minutesOnesDigit = minutes - (minutesTensDigit * 10);

    if(hoursTensDigit == 0) {
        // Blank the hours tens digit if it's 0
        hoursTensDigit = -1;
    }

	sendBitToTubeDrivers(0);	// NC
	sendBitToTubeDrivers(0);	// NC
	sendBitToTubeDrivers(0);	// NC
	sendBitToTubeDrivers(0);	// NC

    sendBitsToTubeDriversToDisplayNumber(minutesTensDigit, 0);
    sendBitsToTubeDriversToDisplayNumber(minutesOnesDigit, 0);

	sendBitToTubeDrivers(0);	// NC
	sendBitToTubeDrivers(0);	// NC
	sendBitToTubeDrivers(0);	// NC
	sendBitToTubeDrivers(0);	// NC

    sendBitsToTubeDriversToDisplayNumber(hoursOnesDigit, 1);
    sendBitsToTubeDriversToDisplayNumber(hoursTensDigit, 1);

	latchTubeDrivers();
}

void sendBitsToTubeDriversToDisplayNumber(int8_t number, uint8_t direction) {
    if(number < 0 || number > 9) {
        for(uint8_t i = 0; i < 8; i++) {
            sendBitToTubeDrivers(0);
        }
    } else if(direction == 0) {
        for(int8_t i = 0; i < 8; i++) {
            sendBitToTubeDrivers(numberPatterns[number][i]);
        }
    } else {
        for(int8_t i = 7; i >= 0; i--) {
            sendBitToTubeDrivers(numberPatterns[number][i]);
        }
    }
}

void sendBitToTubeDrivers(uint8_t bit) {
	// Set DIN according to the bit
	if(bit == 0) {
		// Set DIN to 0
		PORTB &= ~_BV(PINB3);
	} else {
		// Set DIN to 1
		PORTB |= _BV(PINB3);
	}

	// Toggle the clock, 1 then 0
	PORTB |= _BV(PINB4);
	PORTB &= ~_BV(PINB4);
}

void latchTubeDrivers() {
	// Toggle LATCH, 1 then 0
	PORTB |= _BV(PINB2);
	PORTB &= ~_BV(PINB2);
}

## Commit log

2014-04-14 Starting the BOM to order some initial parts
    [bom.ods]
2014-04-15 Full BOM (so far)
    [bom.ods]
2014-04-26 Tweaking the PWM stuff
2014-04-26 Cleaned up the code, got the boost voltage monitor/feedback loop working
2014-04-27 Working on a breakout board for IV-11 tubes
    [iv-11_breakout.brd, iv-11_breakout.sch]
2014-04-27 New layout for the IV-11 breakout, fixed the drill size
    [iv-11_breakout.sch]
2014-04-27 Generated Gerber files and sent it off for fabrication
    [iv-11_breakout.brd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]
2014-04-28 Things get weird with more than one tube connected
2014-05-06 Working on interfacing with the tube drivers
2014-05-22 Trying desperately to get Timer2 to give me some PWM
2014-11-15 Starting on the boost supply board, finding parts
    [iv-11_boost_supply.sch]
2014-11-15 Got all the parts in place, also found some more parts
    [iv-11_boost_supply.sch]
2014-11-16 Made a fuse part, got the rest of the parts in place
    [iv-11_boost_supply.brd, iv-11_boost_supply.sch]
2014-11-19 Did most of the board layout, found more parts to order
    [iv-11_boost_supply.brd, iv-11_boost_supply.sch]
2014-12-22 Cleaned up the board layout, need the parts to test it out on paper
    [iv-11_boost_supply.brd, iv-11_boost_supply.sch]
2014-12-22 Not entirely sure what changed here, but Eagle wanted to save things
    [iv-11_boost_supply.brd]
2015-02-05 Finalizing the layout
    [iv-11_boost_supply.brd]
2015-02-05 First draft of routing
    [iv-11_boost_supply.brd]
2015-02-09 Making component names more visible on the board
    [iv-11_boost_supply.brd]
2015-02-09 Adding some labeling to the boost supply board
    [iv-11_boost_supply.brd]
2015-02-12 Tested the layout for the boost supply board, specified that it's rev A
    [iv-11_boost_supply.brd]
2015-02-12 Working on rev B of the boost supply board
    [iv-11_boost_supply.brd, iv-11_boost_supply.sch]
2015-02-12 Finished up rev B of the boost supply board, but the layout still needs to be tested
    [iv-11_boost_supply.brd, iv-11_boost_supply.sch]
2015-02-12 Made a pdf for the current boost supply board
2015-02-12 Turned layers on
    [iv-11_boost_supply.brd]
2016-04-04 Starting on the main board
    [ice_tube_clock.sch, iv-11_boost_supply.brd]
2016-04-04 More big parts
    [ice_tube_clock.sch]
2016-04-06 Starting on basic layout of the board
    [ice_tube_clock.brd, ice_tube_clock.sch]
2016-04-12 I thought I committed all this stuff
    [bom.ods, iceTubeClockAssembly.iam, iceTubeClockAssemblyRevised.iam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]
2016-04-18 Finalized the VFD driver carrier board
    [iceTubeClockCircuitBoard.3dm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]
2016-04-19 Cleaning out stuff related to active power supply regulation, won't need that
    [main.c]
2016-04-19 Add support for a real time clock based on an external oscillator
    [main.c]
2016-04-26 Getting the firmware to work with the PCB, cleaning it up

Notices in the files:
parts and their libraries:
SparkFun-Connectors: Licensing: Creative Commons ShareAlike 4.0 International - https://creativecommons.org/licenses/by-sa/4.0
